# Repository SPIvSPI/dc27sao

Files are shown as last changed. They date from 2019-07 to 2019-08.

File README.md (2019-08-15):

# dc27sao

	███████╗██████╗ ██╗██╗   ██╗███████╗██████╗ ██╗
	██╔════╝██╔══██╗██║██║   ██║██╔════╝██╔══██╗██║
	███████╗██████╔╝██║██║   ██║███████╗██████╔╝██║
	╚════██║██╔═══╝ ██║╚██╗ ██╔╝╚════██║██╔═══╝ ██║
	███████║██║     ██║ ╚████╔╝ ███████║██║     ██║
	╚══════╝╚═╝     ╚═╝  ╚═══╝  ╚══════╝╚═╝     ╚═╝

Blackhat spy &amp; Whitehat spy SAO from Def Con 27

The pencil sketch that started it all on June 14th:

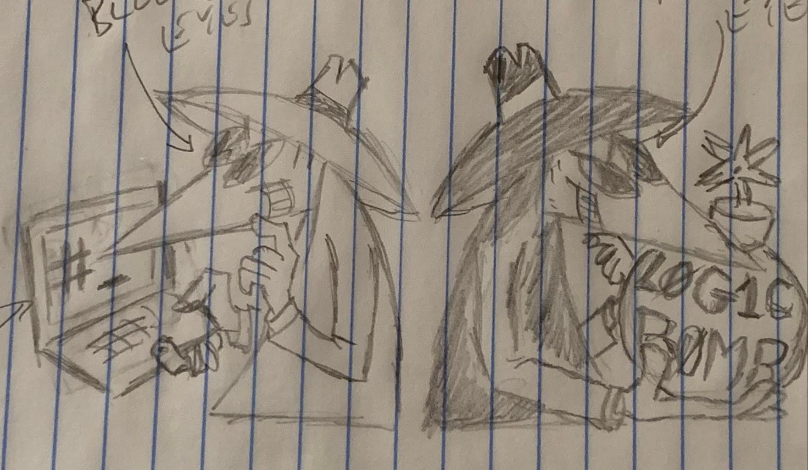
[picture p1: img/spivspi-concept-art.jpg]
concept art


Bling bling:

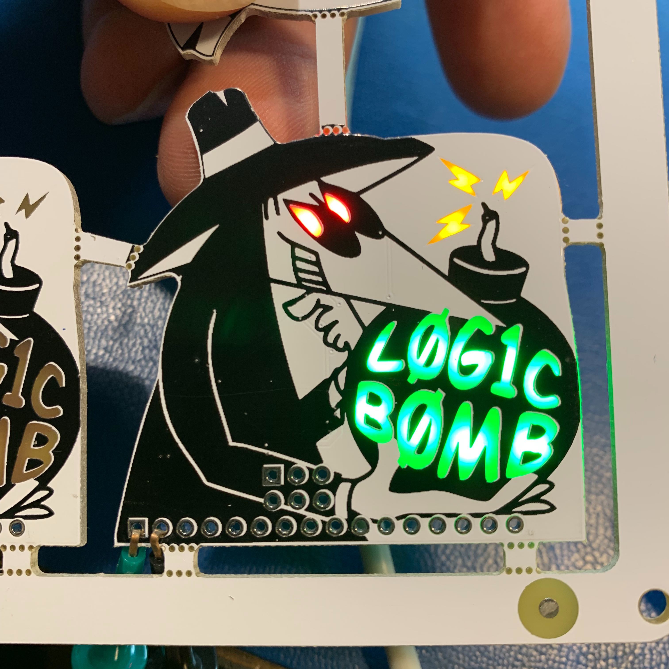
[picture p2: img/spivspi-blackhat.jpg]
blackhat


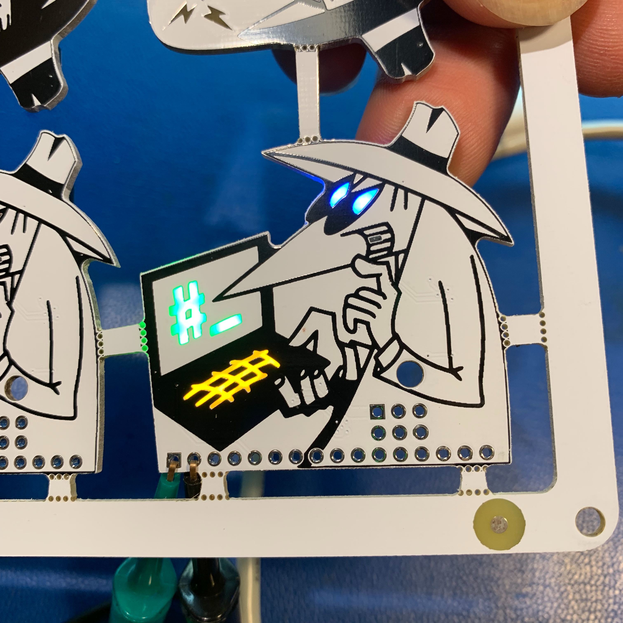
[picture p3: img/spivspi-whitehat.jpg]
whitehat


## WTF is all this crap

- `/firmware` - shitty code that runs the blinkenlites
- `/gui` - not-so-shitty gui animation code generator tool (with shittyness added in a rush at the end)
- `/hardware` - schematics and pcb stuff
- `/img` - some pix from the adventure

## Other crap

- The twitters https://twitter.com/SPIvSPI
- Hackaday page https://hackaday.io/project/166811-spivspi-sao-dc27-badge

## Guilty Parties

```
xres0nance - Hardware & firmware
steve/corelit - Over-excellent GUI animation tool
```

## Shoutz n Greetz

```
true, cprossu, aask, & WP crew - 8051 wisdom and moral support
jrwr - crazy drunk russians and a dope-ass hat
MCB - melted lead shoulder-to-shoulder, six pins at a time
woodencyborg - for diving in the deep end with us
pcbway - haulin' ass, gettin' paid
```

and thanks to all our other cheerleaders! couldn't have done it without ya.

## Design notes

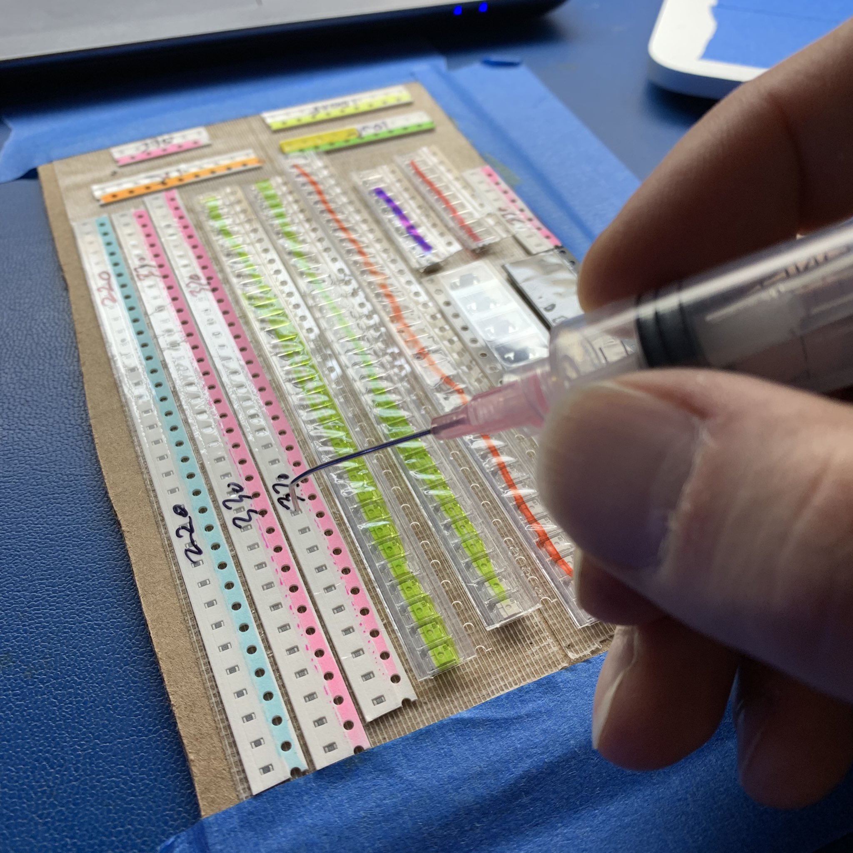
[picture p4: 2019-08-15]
img/picking-and-placing.jpg

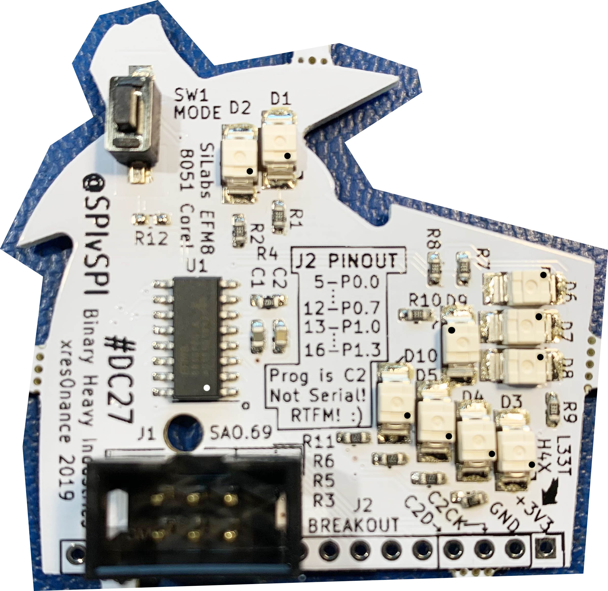
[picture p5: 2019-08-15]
img/svs-white-pcb-photo.jpg

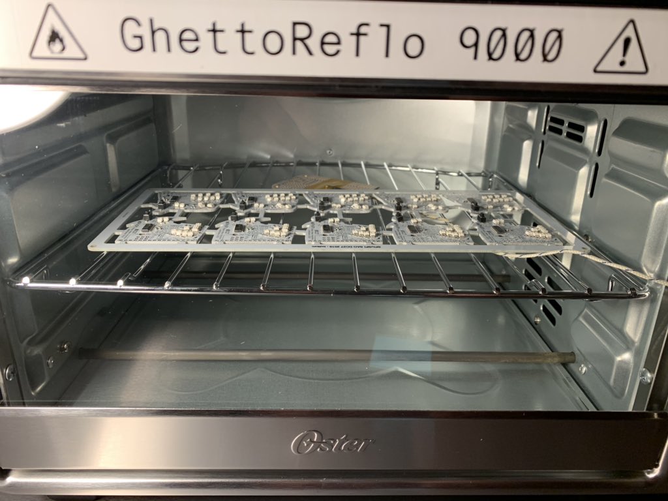
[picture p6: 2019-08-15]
img/ghetto-reflo-9000.jpg

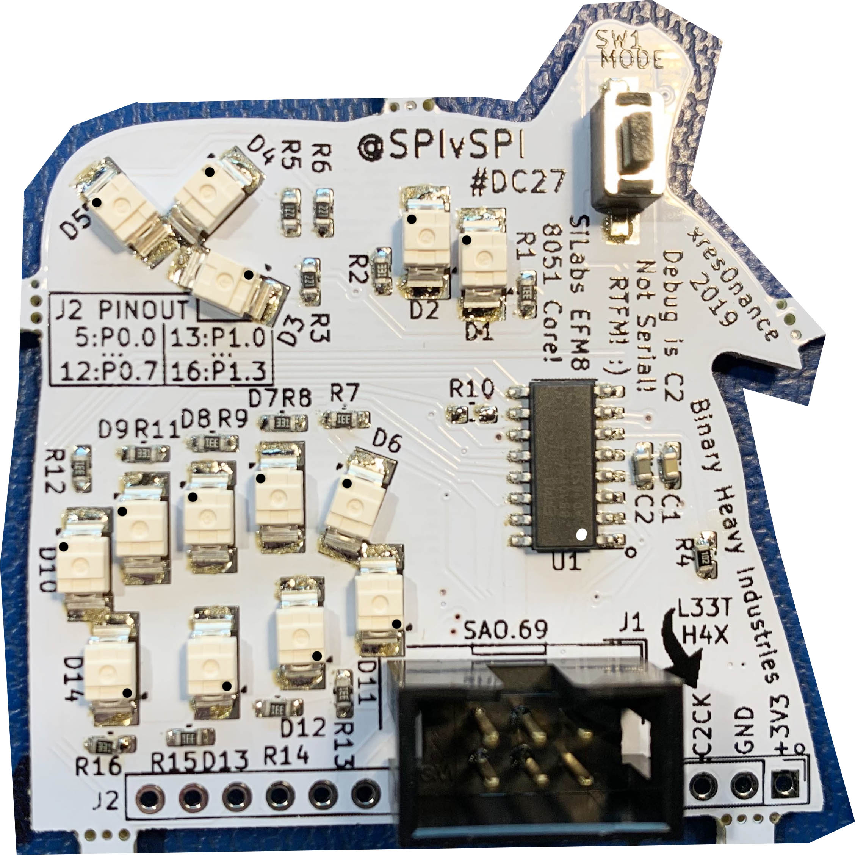
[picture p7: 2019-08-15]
img/svs-black-pcb-photo.jpg

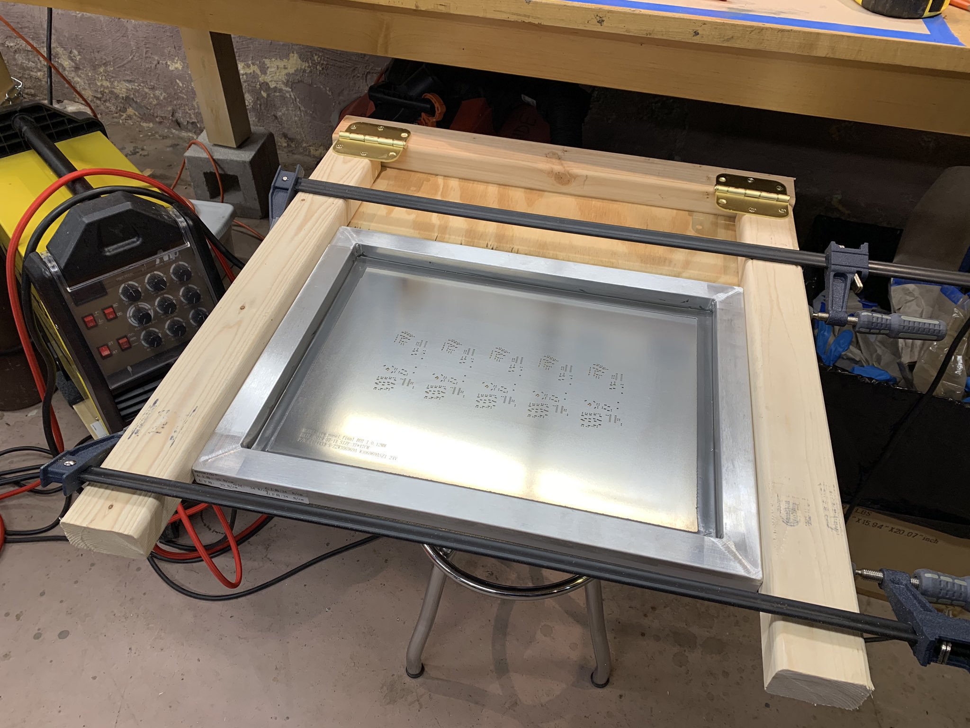
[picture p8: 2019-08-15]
img/ghetto-paste-jig.jpg

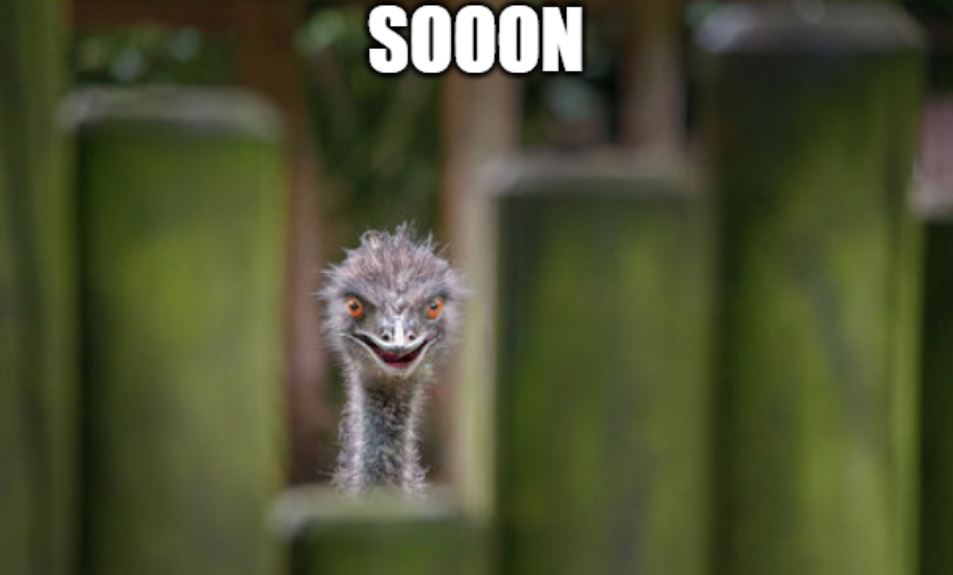
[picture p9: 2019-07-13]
img/soon.jpg

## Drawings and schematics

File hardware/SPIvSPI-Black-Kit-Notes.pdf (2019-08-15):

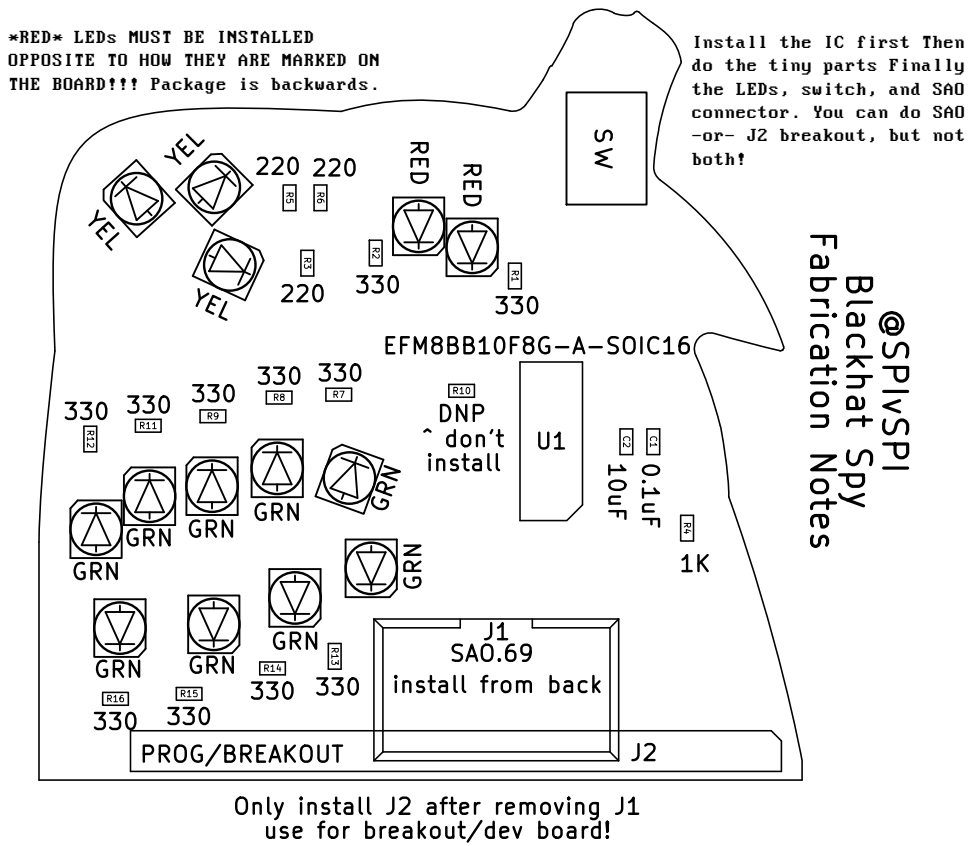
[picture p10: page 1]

*RED* LEDs MUST BE INSTALLED
OPPOSITE TO HOW THEY ARE MARKED ON
THE BOARD!!! Package is backwards.

Install the IC first Then
do the tiny parts Finally
the LEDs, switch, and SAO
connector. You can do SAO
-or- J2 breakout, but not
both!

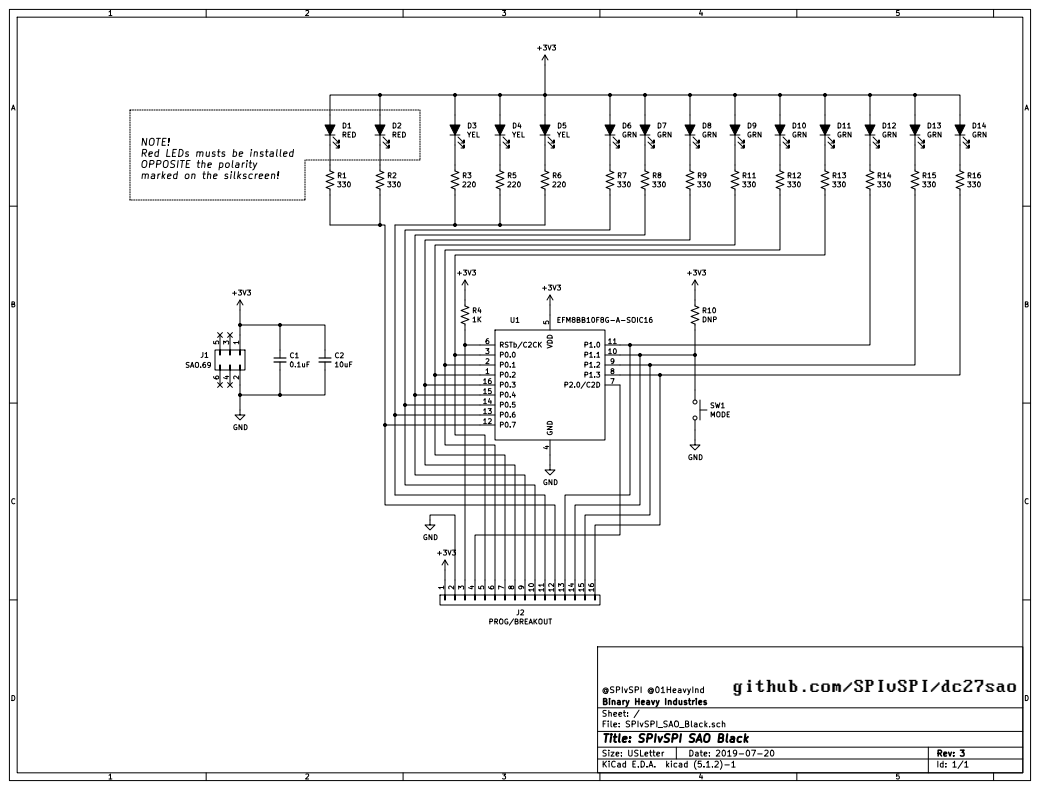
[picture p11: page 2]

github.com/SPIvSPI/dc27sao

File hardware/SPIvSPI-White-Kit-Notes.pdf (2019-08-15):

### oSPlvSPI Whitehat Spy

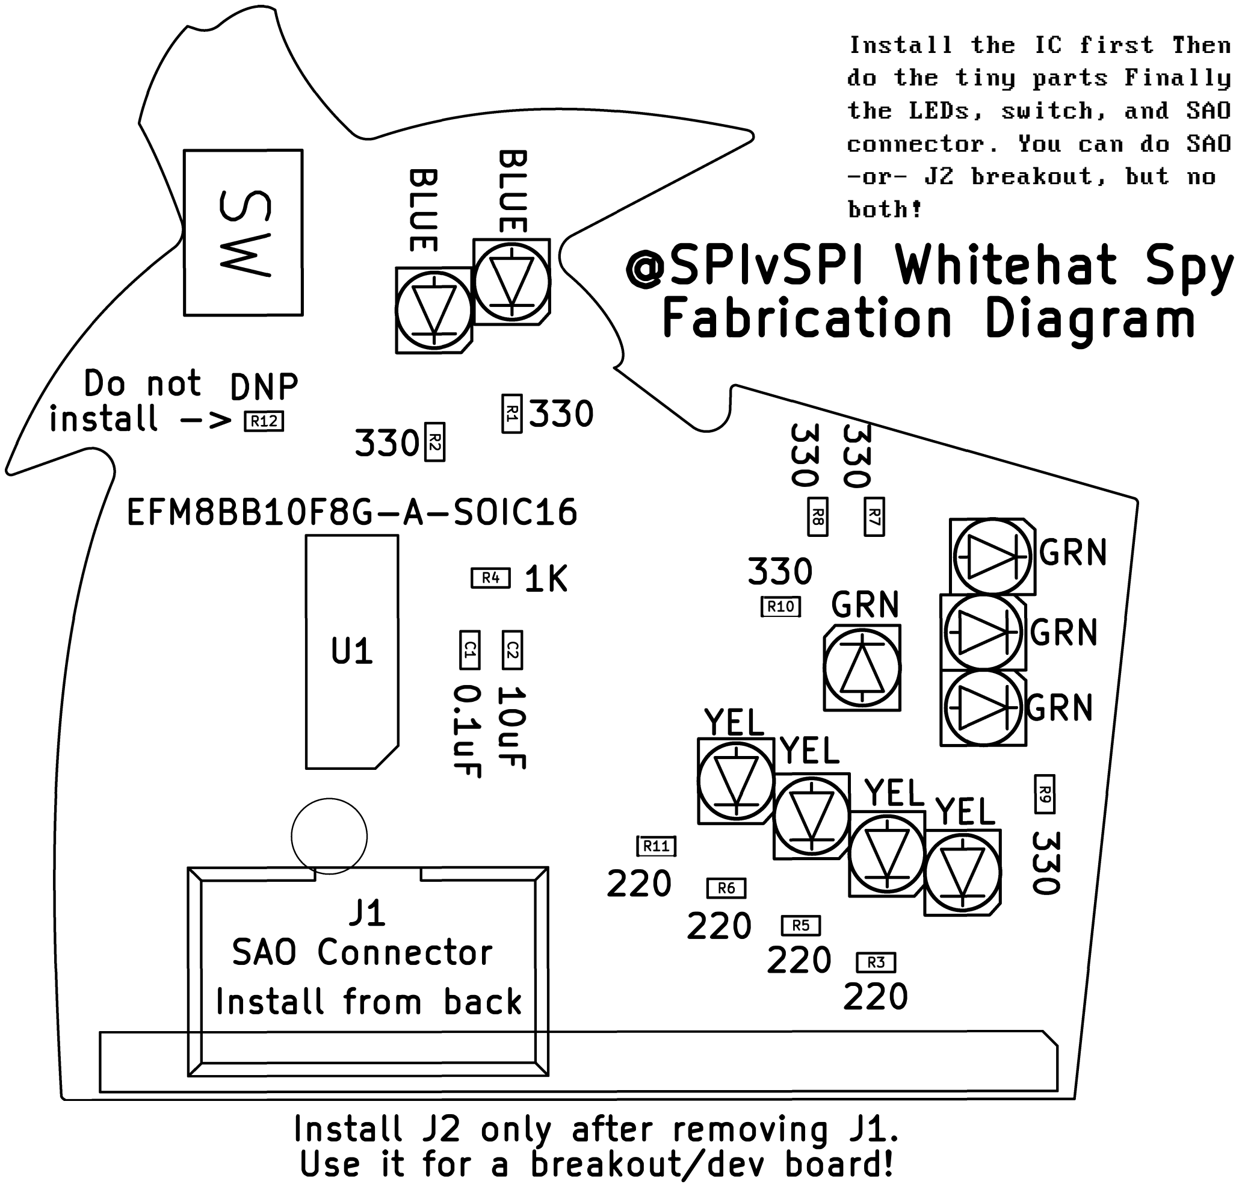
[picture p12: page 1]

330@] @1330

EFM8BBiOF8G-A-SOICi6
| m:J iK
Ui

Ji

0
•
C: 0
C:
"'Tl "'Tl

SAO Connector
Install from back

### Fabrication Diagram

!R11!
220

ul

0

ul
0

ul
330

!R10! GRN

220 oo
220 C£J
220

Install J2 only after removing Ji. Use it for a breakout/dev board!

Install the IC first Then
do the tiny parts Finally
the LEDs, switch, and SAO
connector. You can do SAO
-or- J2 breakout, but no
both!

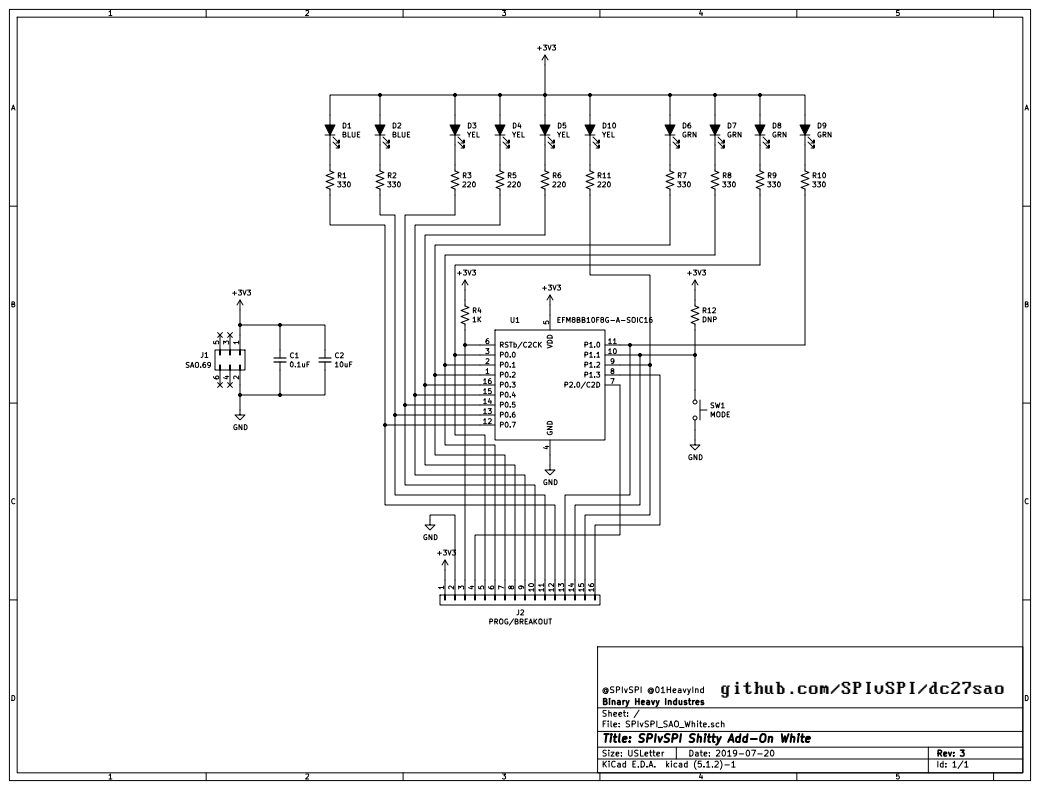
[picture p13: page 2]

github.com/SPIvSPI/dc27sao

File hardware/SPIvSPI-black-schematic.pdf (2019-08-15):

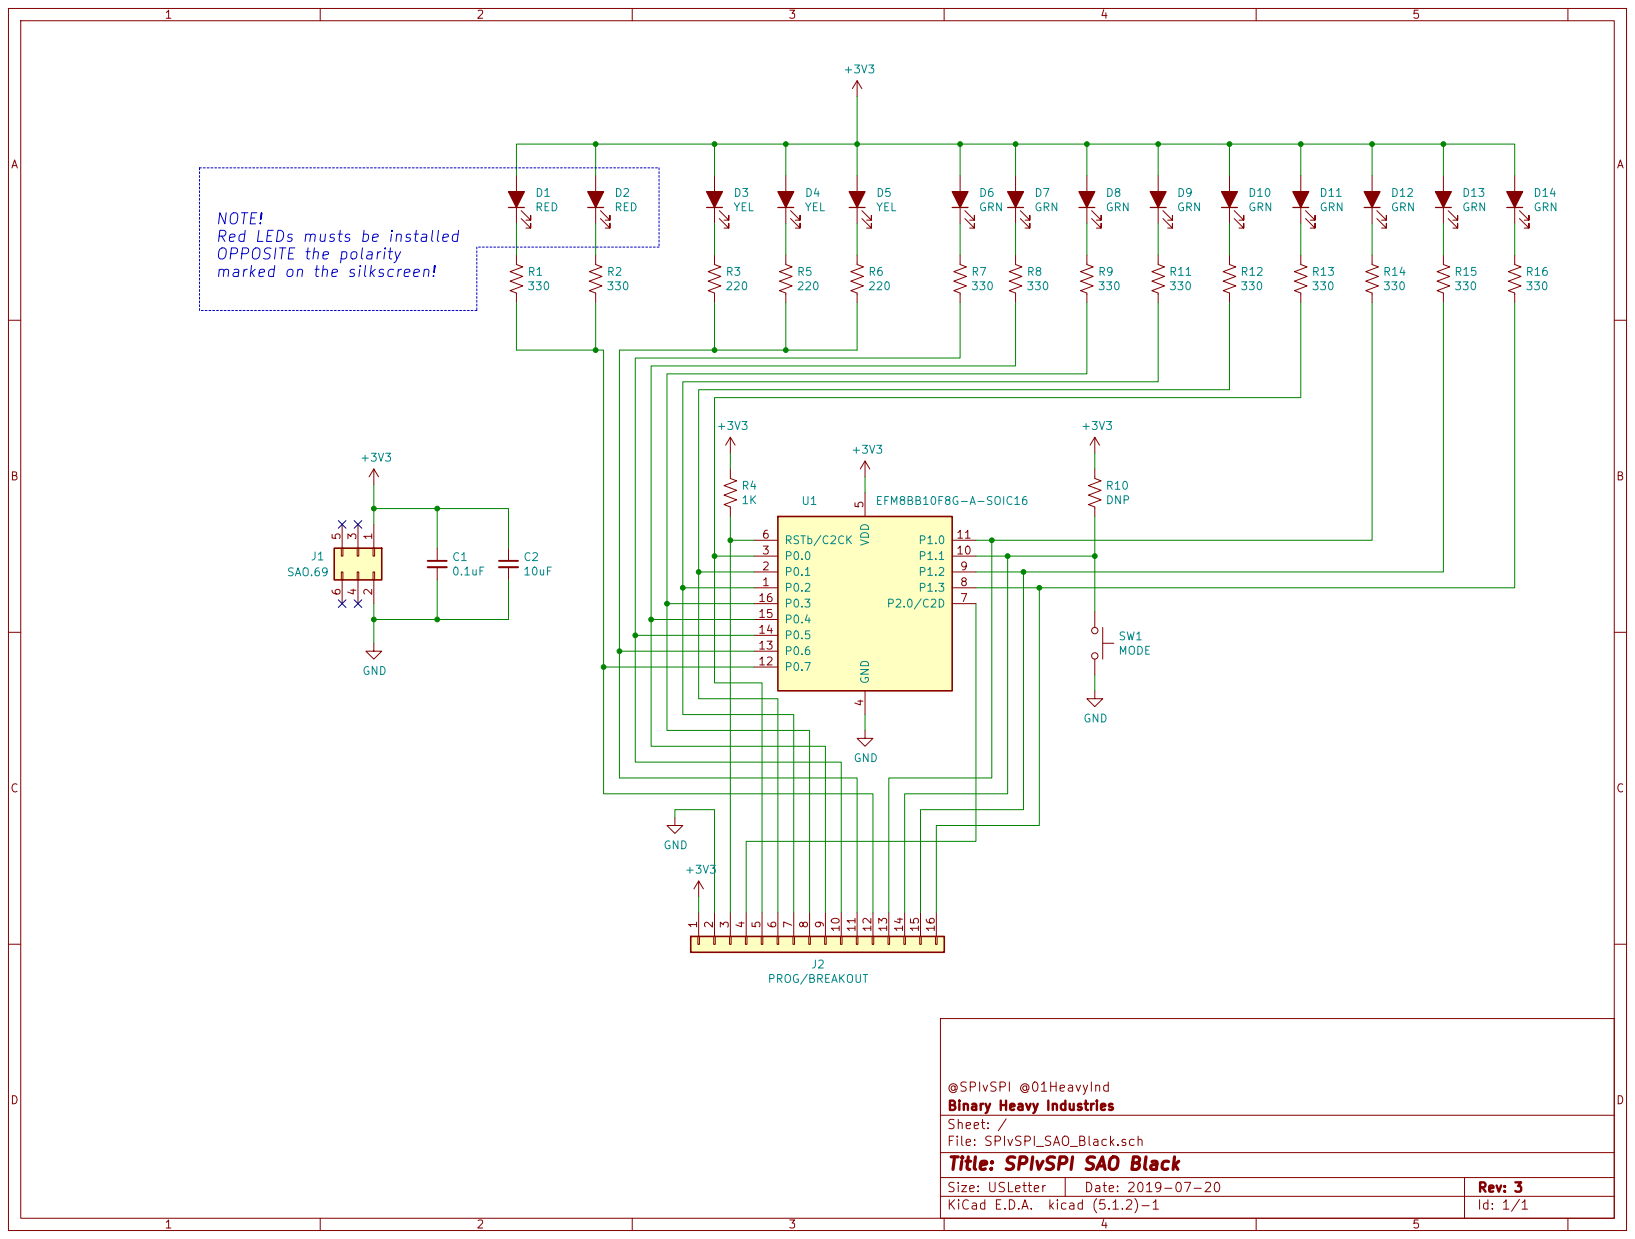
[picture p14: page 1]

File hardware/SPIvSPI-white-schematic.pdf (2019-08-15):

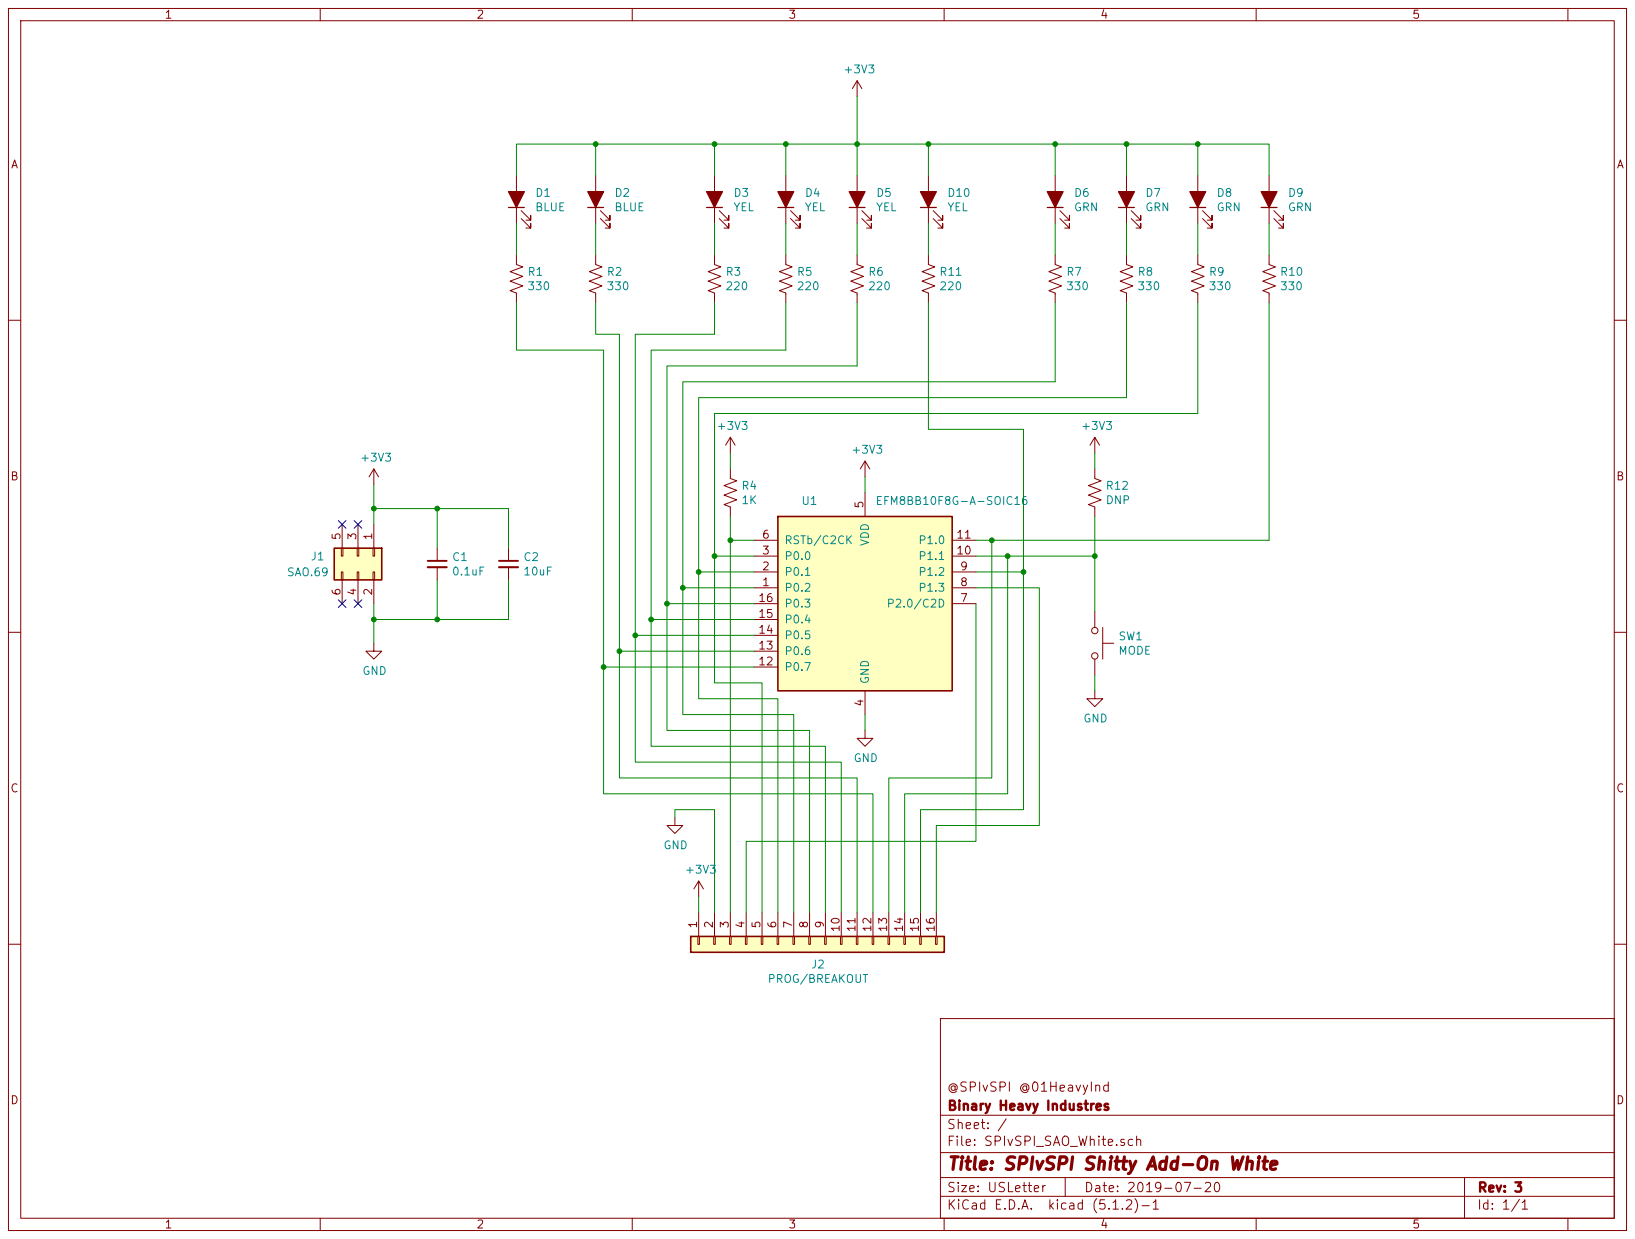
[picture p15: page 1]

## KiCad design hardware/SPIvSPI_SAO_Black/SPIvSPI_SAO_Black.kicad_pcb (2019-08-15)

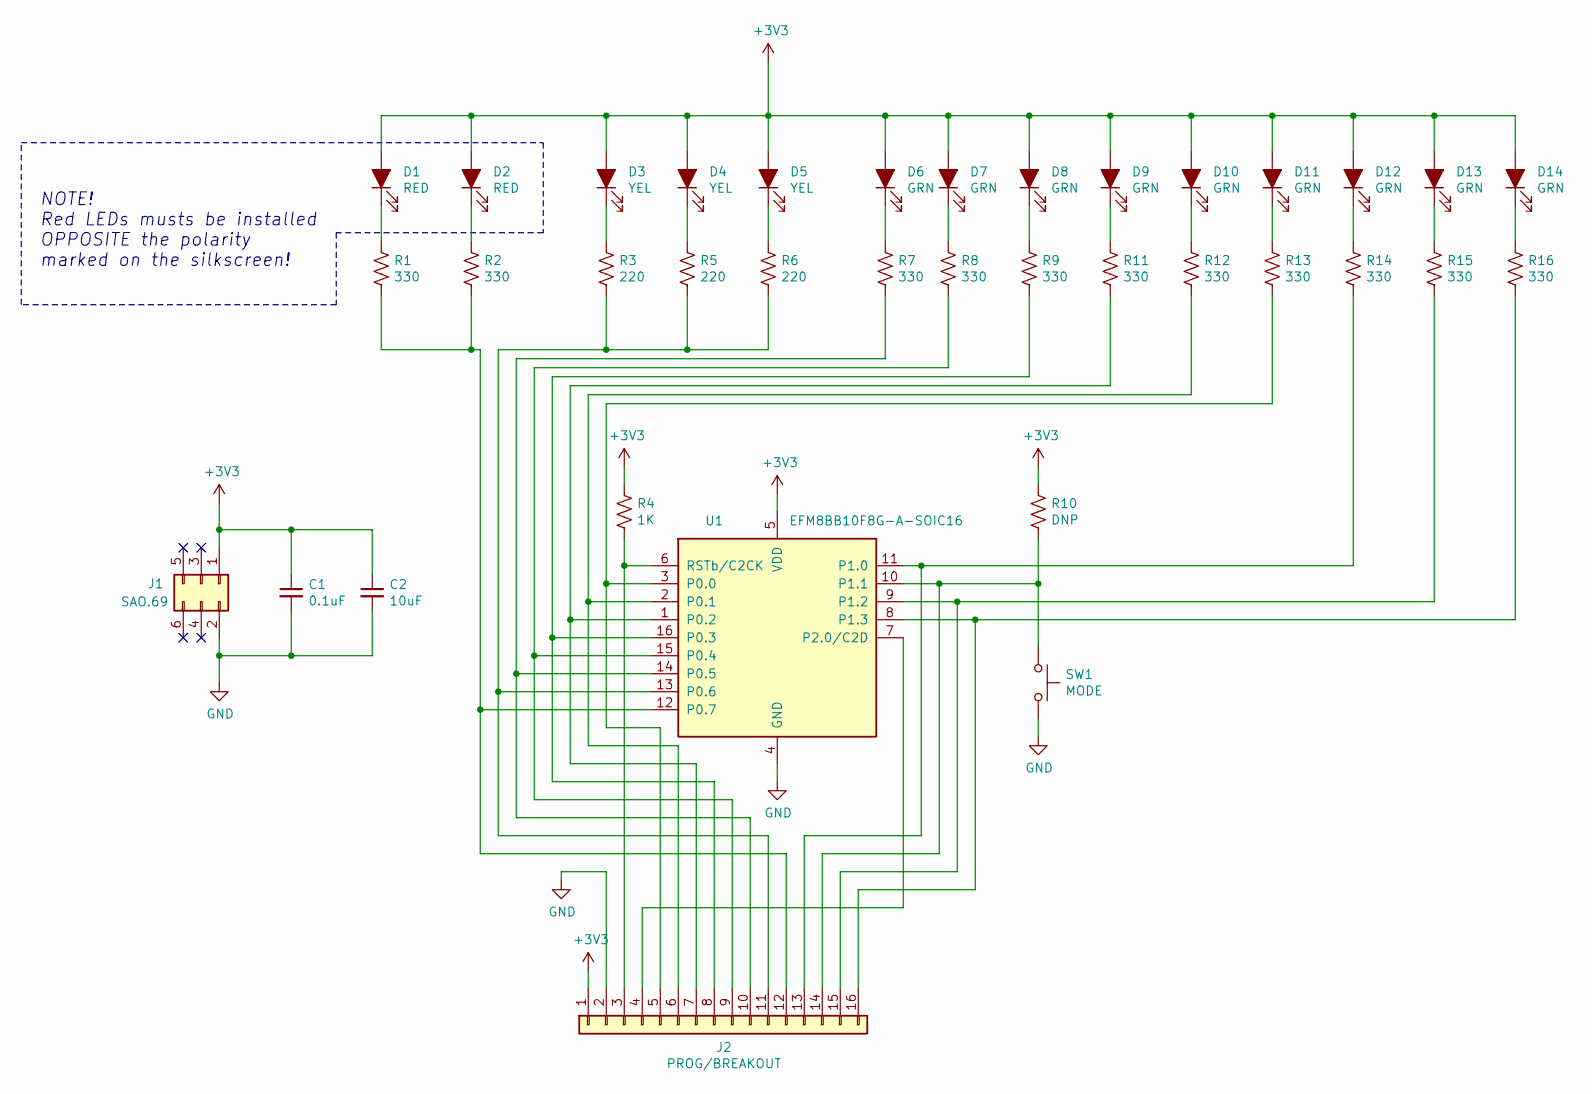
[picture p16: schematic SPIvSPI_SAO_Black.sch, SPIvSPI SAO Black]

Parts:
C1: 0.1uF; C_0603_1608Metric_Pad1.05x0.95mm_HandSolder
C2: 10uF; C_0603_1608Metric_Pad1.05x0.95mm_HandSolder
D1, D2: RED; SunLED_3.2x2.8mm_PLCC2_bottom
D3, D4, D5: YEL; SunLED_3.2x2.8mm_PLCC2_bottom
D6, D7, D8, D9, D10, D11, D12, D13, D14: GRN; SunLED_3.2x2.8mm_PLCC2_bottom
J1: SAO.69; IDC-Header_2x03_P2.54mm_Vertical
J2: PROG/BREAKOUT; PinHeader_1x16_P2.54mm_Vertical
R1, R2, R7, R8, R9, R11, R12, R13, R14, R15, R16: 330; R_0603_1608Metric_Pad1.05x0.95mm_HandSolder
R3, R5, R6: 220; R_0603_1608Metric_Pad1.05x0.95mm_HandSolder
R4: 1K; R_0603_1608Metric_Pad1.05x0.95mm_HandSolder
R10: DNP; R_0603_1608Metric_Pad1.05x0.95mm_HandSolder
SW1: MODE; C&K_PTS636_SMD_Tact_6.0x3.5_BACK
U1: EFM8BB10F8G-A-SOIC16; SOIC-16_3.9x9.9mm_P1.27mm

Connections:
+3V3: C1.1, C2.1, D1.2 (A), D2.2 (A), D3.2 (A), D4.2 (A), D5.2 (A), D6.2 (A), D7.2 (A), D8.2 (A), D9.2 (A), D10.2 (A), D11.2 (A), D12.2 (A), D13.2 (A), D14.2 (A), J1.1, J2.1, R4.1, R10.1, U1.5 (VDD)
GND: C1.2, C2.2, J1.2, J2.2, SW1.2, U1.4 (GND)
unnamed: D1.1 (K), R1.1
unnamed: D2.1 (K), R2.1
unnamed: D3.1 (K), R3.1
unnamed: D4.1 (K), R5.1
unnamed: D5.1 (K), R6.1
unnamed: D6.1 (K), R7.1
unnamed: D7.1 (K), R8.1
unnamed: D8.1 (K), R9.1
unnamed: D9.1 (K), R11.1
unnamed: D10.1 (K), R12.1
unnamed: D11.1 (K), R13.1
unnamed: D12.1 (K), R14.1
unnamed: D13.1 (K), R15.1
unnamed: D14.1 (K), R16.1
unnamed: J2.3, R4.2, U1.6 (RSTb/C2CK)
unnamed: J2.4, U1.7 (P2.0/C2D)
unnamed: J2.5, R13.2, U1.3 (P0.0)
unnamed: J2.6, R12.2, U1.2 (P0.1)
unnamed: J2.7, R11.2, U1.1 (P0.2)
unnamed: J2.8, R9.2, U1.16 (P0.3)
unnamed: J2.9, R8.2, U1.15 (P0.4)
unnamed: J2.10, R7.2, U1.14 (P0.5)
unnamed: J2.11, R3.2, R5.2, R6.2, U1.13 (P0.6)
unnamed: J2.12, R1.2, R2.2, U1.12 (P0.7)
unnamed: J2.13, R14.2, U1.11 (P1.0)
unnamed: J2.14, R10.2, SW1.1, U1.10 (P1.1)
unnamed: J2.15, R15.2, U1.9 (P1.2)
unnamed: J2.16, R16.2, U1.8 (P1.3)

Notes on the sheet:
NOTE! Red LEDs musts be installed OPPOSITE the polarity marked on the silkscreen!

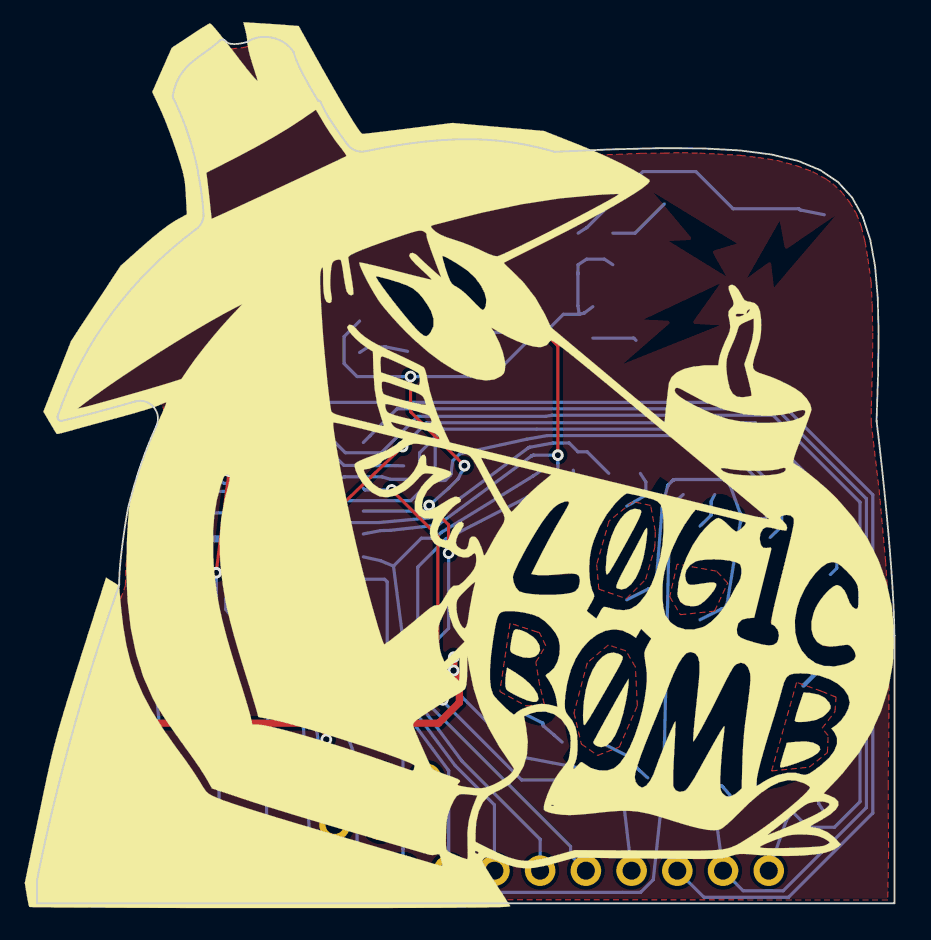
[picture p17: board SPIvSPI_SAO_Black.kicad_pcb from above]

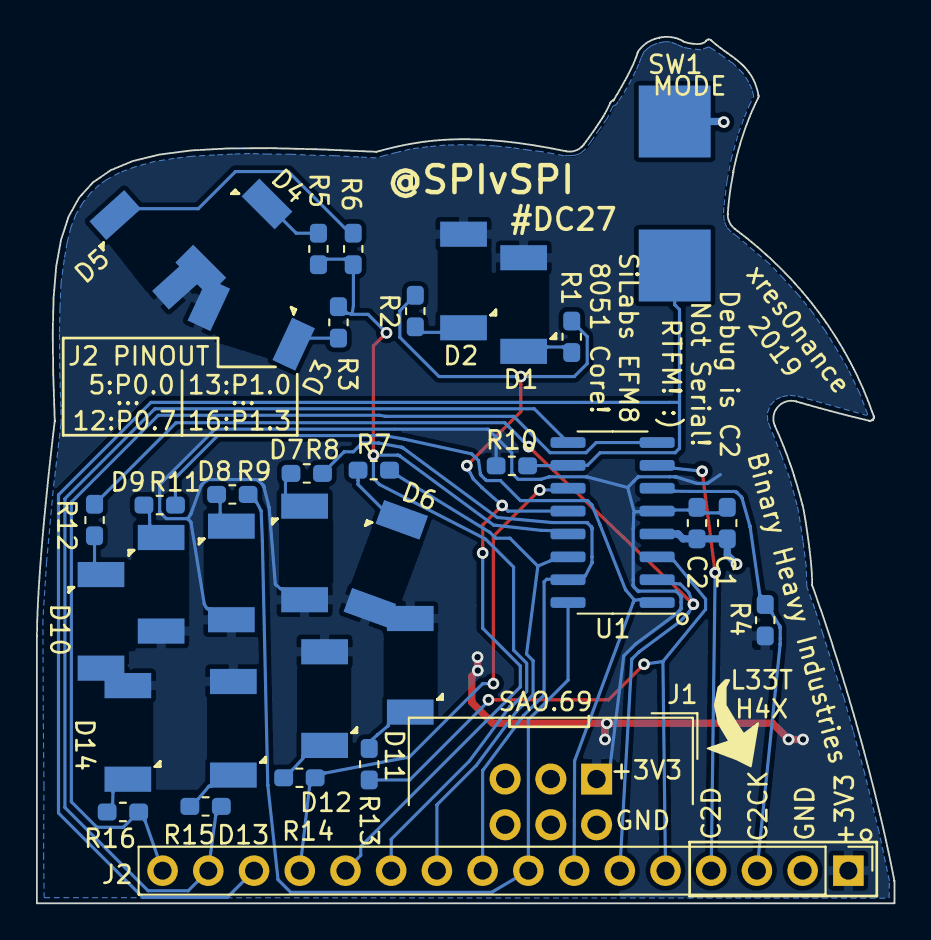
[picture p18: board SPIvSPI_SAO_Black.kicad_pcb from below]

Board: 2 copper layers, 47.6 x 48.1 mm, 36 parts (36 on the bottom side), 30 nets.
